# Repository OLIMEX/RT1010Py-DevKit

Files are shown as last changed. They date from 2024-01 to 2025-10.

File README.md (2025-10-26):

# RT1010Py-DevKit
Development board for RT1010Py board

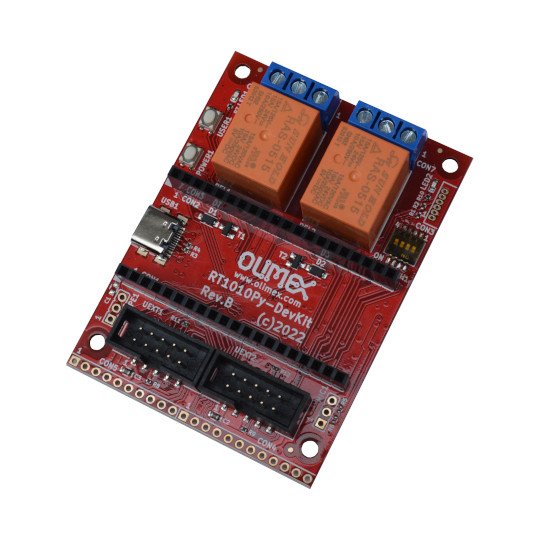
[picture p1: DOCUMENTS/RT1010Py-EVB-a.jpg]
RT1010Py-EVB-a


https://www.olimex.com/Products/MicroPython/RT1010Py-DevKit/open-source-hardware

Features:

* RT1010Py socket connector
* Two UEXT connectors
* Two Relays 10A/250VAC
* USB-C power supply
* Two buttons
* Boot configuration slide switch
* Dimensions: (55 x 75)mm ~ (2.17 x 2.95)"

## Documentation

Check the files in OLIMEX/RT1010Py-DevKit/__DOCUMENTS__ for ressources:

* [RT1010Py-DevKit user manual](DOCUMENTS/RT1010Py-DevKit-user-manual.pdf) (pdf)
* [RT1010Py-DevKit edge connector PinOut](DOCUMENTS/RT1010Py-EVB-edge-connector.jpg) (jpg)
* [RT1010Py-DevKit UEXT PinOut](DOCUMENTS/RT1010Py-EVB-UEXT) (jpg)

See also the [RT1010-Py Microcontroler documentation](https://github.com/OLIMEX/RT1010Py) on its own repository.

## Licenses

* Hardware is released under CERN Open Hardware Licence Version 2 - Strongly Reciprocal, all silkscreen credits to Olimex should remain;
* Software is released under GPL3 Licensee
* Documentation is released under CC BY-SA 4.0

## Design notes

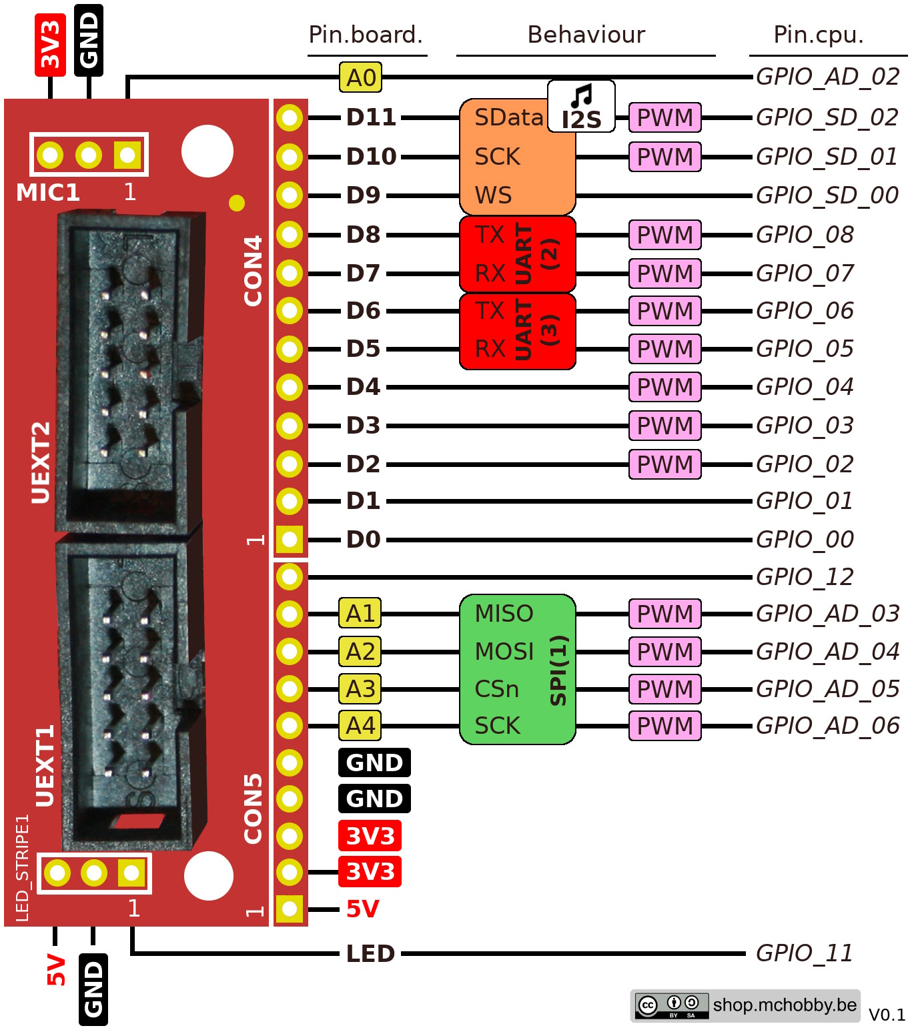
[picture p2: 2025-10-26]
DOCUMENTS/RT1010Py-EVB-edge-connector.jpg

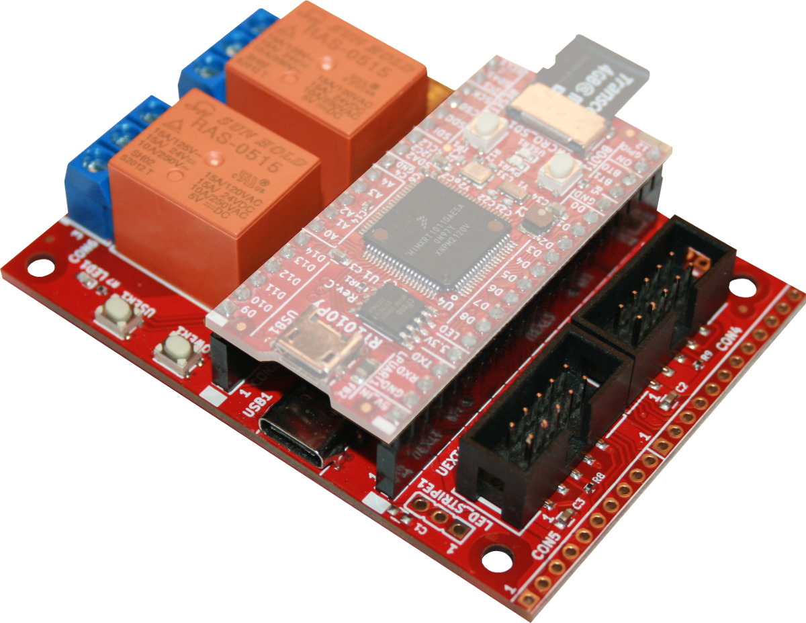
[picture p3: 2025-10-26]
DOCUMENTS/RT1010Py-EVB-b.jpg

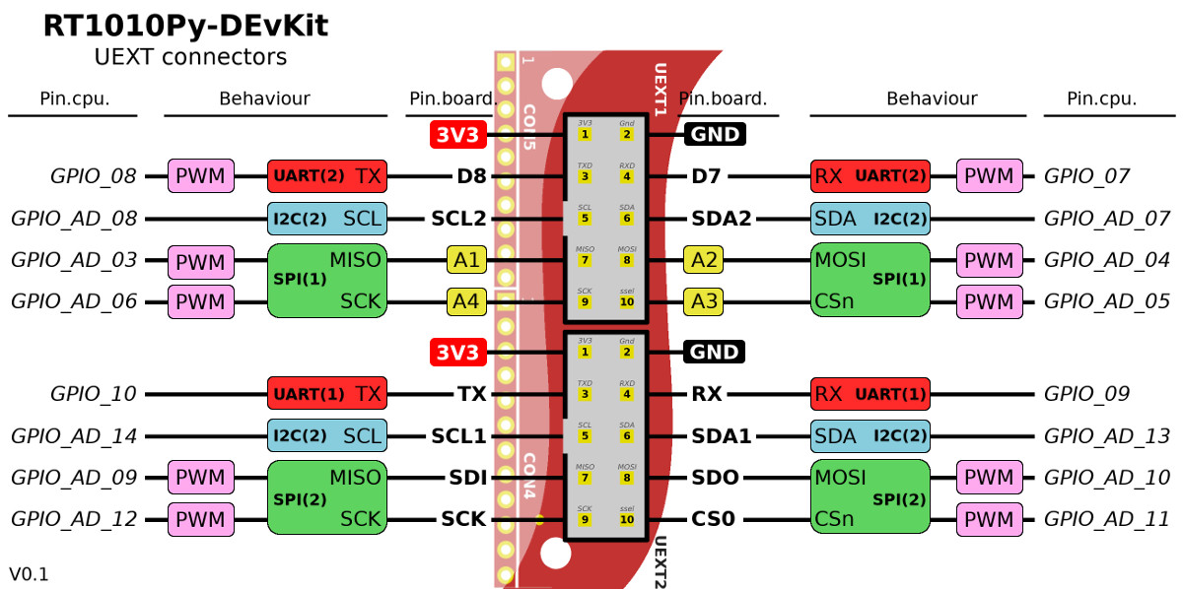
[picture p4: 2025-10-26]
DOCUMENTS/RT1010Py-EVB-UEXT.jpg

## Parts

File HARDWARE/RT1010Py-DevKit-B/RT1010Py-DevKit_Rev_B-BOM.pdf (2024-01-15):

RT1010Py-DevKit_Rev_B-BOM | 06/29/2022
Qty Designation | Package | Designator
4 2.2K/0402 | R_0402_5MIL_DWS | R12,R8,R9,R11
2 5.1K/0402 | R_0402_5MIL_DWS | R3,R4
2 10K/0402 | R_0402_5MIL_DWS | R10,R7
2 4.7uF/6.3V/0603 | C_0603_5MIL_DWS | C3,C2
2 LMUN2211LT1G(SOT-23) SOT23 | T1,T2
2 1N4148W | SOD-123_KA | D2,D1
2 LED/Green/0603 | LED_0603_KA | LED2,LED1
2 BH10S(B-D-02x5-LF) | GBH-254-SMT-10 | UEXT2,UEXT1
2 RAS0515 | Relay_RAS-05-15 | REL2,REL1
2 PN1X20(F-D-1X20-LF) | HN1x20 | CON2,CON1
1 PN_F-D-1x10-LF | PN1x10 | CON5
1 PN_F-D-1X12-LF | PN1x12 | CON4
2 DG306-5.0-3P | TB3-5mm | CON7,CON6
1 USB-C-16P-F | USB2.0_TYPE-C(A40-00119-A52-12) | USB1
1 DSHP04TS-S | DSHP04TS-S-1.27mm_Half_4_Slide | SWITCH1
2 T1107A(6x3,8x2,5MM) | YTS-A016-X | POWER1,USER1
2 NA | HN1x3 | LED_STRIPE1,MIC1
1 NA(WU06S) | WU06S | CON3
2 NA(100K) | R_0402_5MIL_DWS | R6,R5
1 NA(4.7uF/6.3V) | C_0603_5MIL_DWS | C1
2 NA(220R) | R_0402_5MIL_DWS | R1,R2

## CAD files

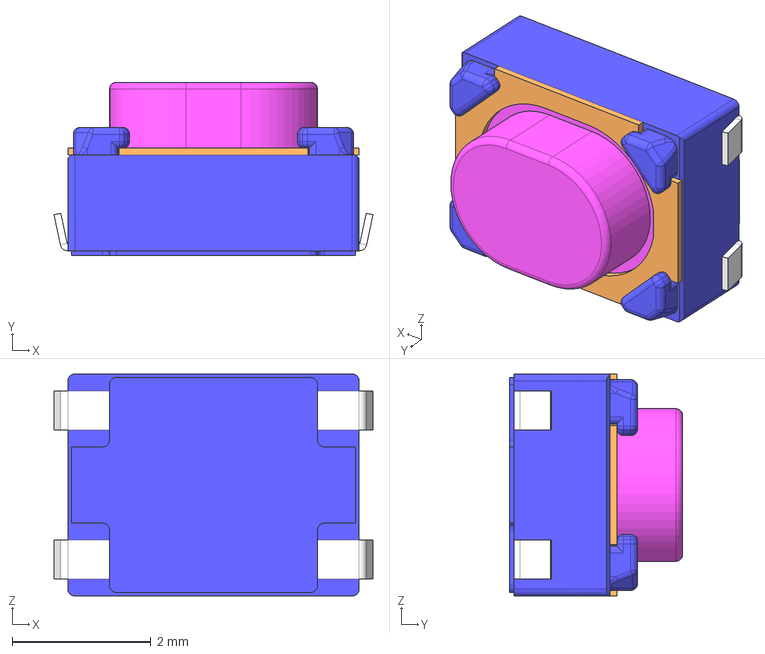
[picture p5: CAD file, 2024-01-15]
HARDWARE/RT1010Py-DevKit-B/3d/YTS-A016-X(SKRPABE010).stp
4.60 x 2.50 x 3.20 mm

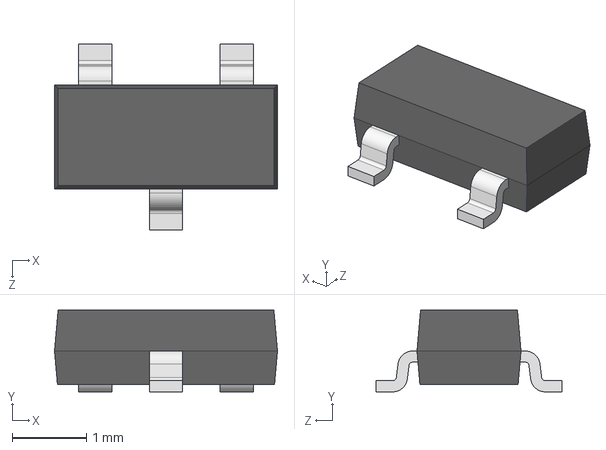
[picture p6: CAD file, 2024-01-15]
HARDWARE/RT1010Py-DevKit-B/3d/SOT-23.step
3.00 x 1.10 x 2.50 mm

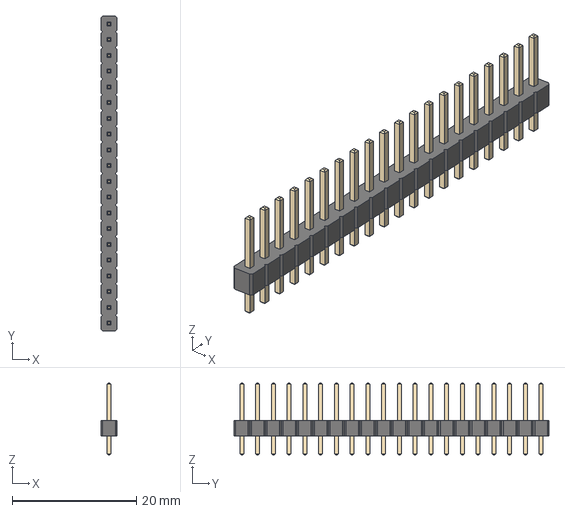
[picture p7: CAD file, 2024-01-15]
HARDWARE/RT1010Py-DevKit-B/3d/HN1x20-PinHeader_1x20_P2.54mm_Vertical.step
2.54 x 50.8 x 11.5 mm

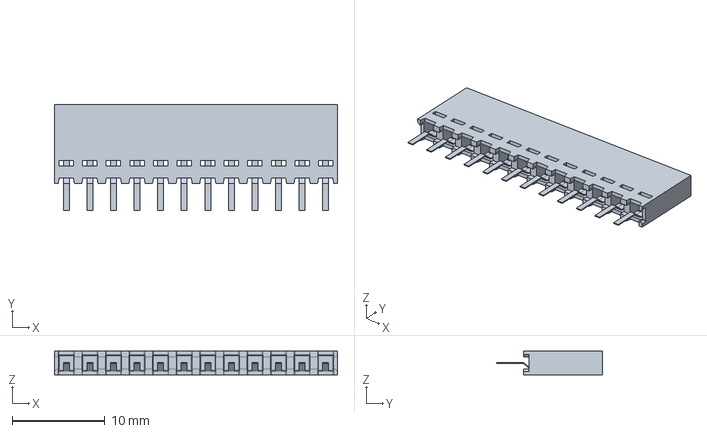
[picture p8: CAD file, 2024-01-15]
HARDWARE/RT1010Py-DevKit-B/3d/PN1x12-Molex_C-Grid_901471112_1x12_P2.54mm_Vertical.step
30.5 x 11.4 x 2.54 mm

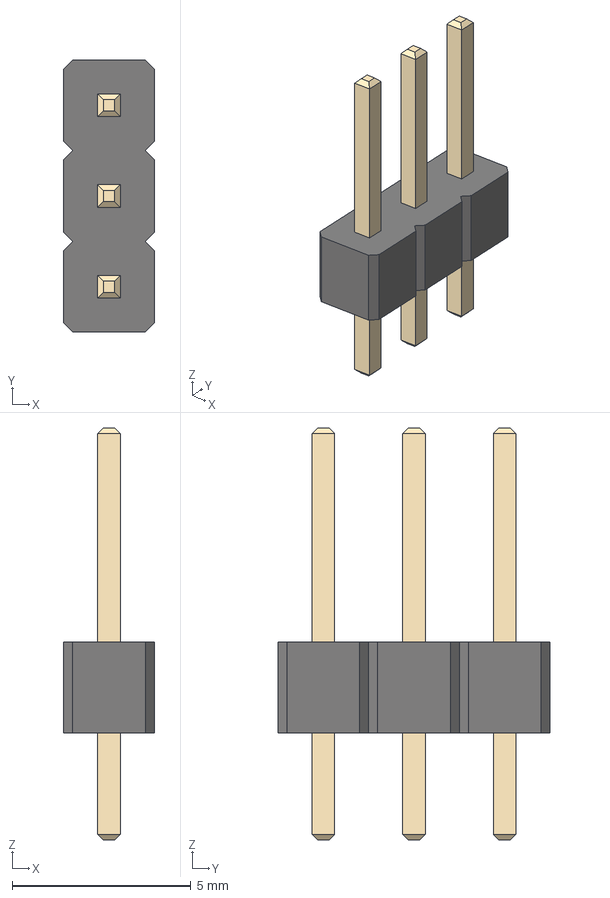
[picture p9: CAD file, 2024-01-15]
HARDWARE/RT1010Py-DevKit-B/3d/HN1x3-PinHeader_1x03_P2.54mm_Vertical.step
2.54 x 7.62 x 11.5 mm

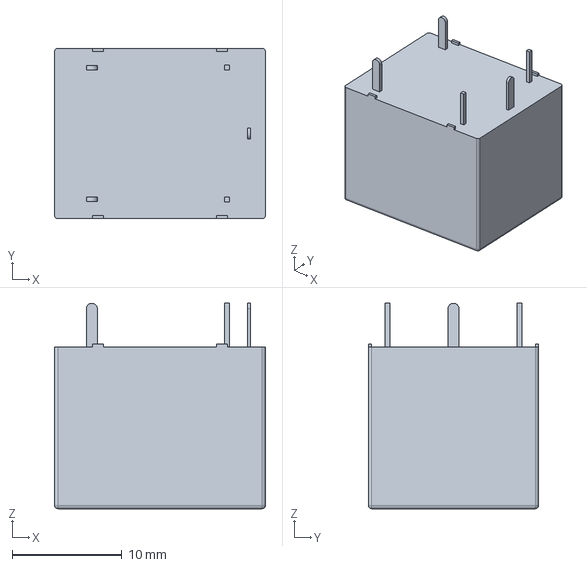
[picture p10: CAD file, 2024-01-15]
HARDWARE/RT1010Py-DevKit-B/3d/TEConnectivity -ORWH-SH-124D1F000.stp
19.2 x 15.5 x 18.7 mm

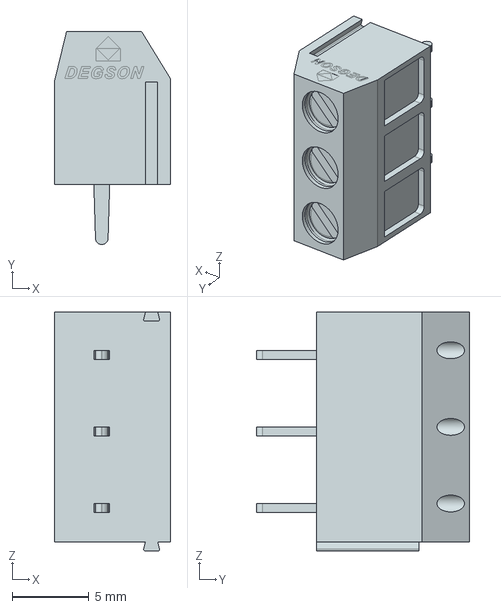
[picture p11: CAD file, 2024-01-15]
HARDWARE/RT1010Py-DevKit-B/3d/TB3-5MM_DG306-5.0-03P-1Y-00A(H).stp
7.60 x 13.9 x 15.6 mm

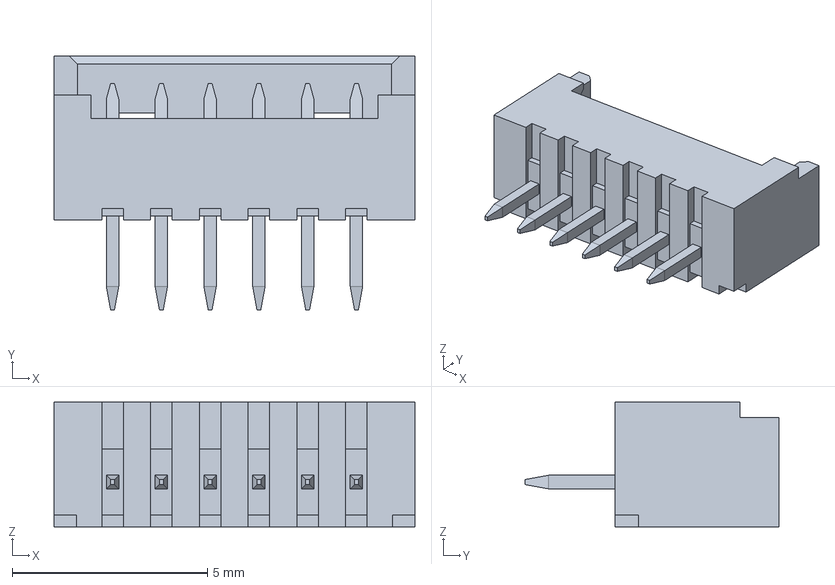
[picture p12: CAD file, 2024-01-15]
HARDWARE/RT1010Py-DevKit-B/3d/WU06S-Molex_PicoBlade_530470610_1x06_P1.25mm_Vertical.step
9.25 x 6.50 x 3.20 mm

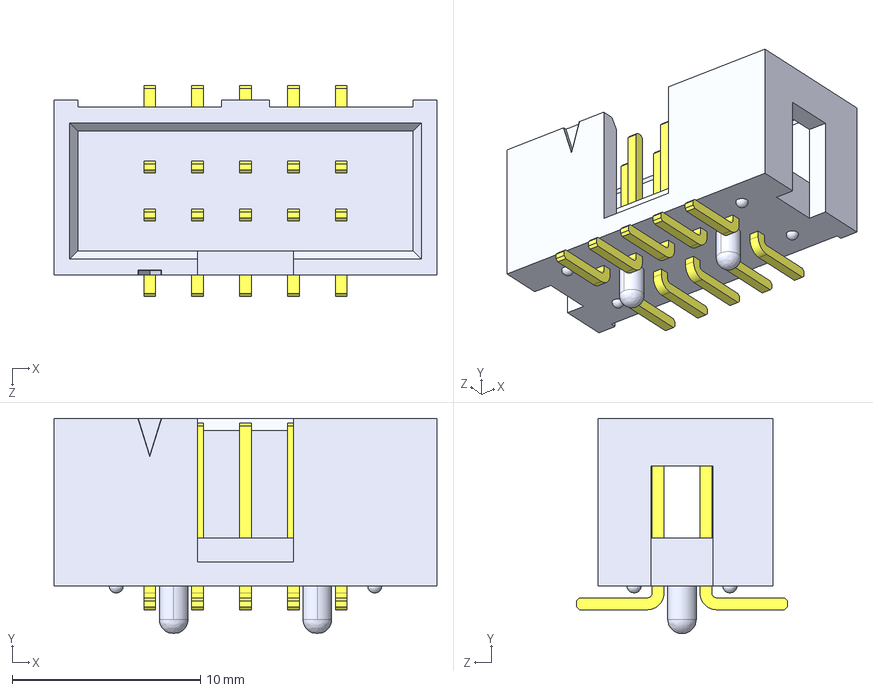
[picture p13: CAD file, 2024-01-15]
HARDWARE/RT1010Py-DevKit-B/3d/UEXT-SMD.STEP
20.3 x 11.4 x 11.2 mm
User Library-HTST-105-01-F-DV-A__HTST-105-01-DV-A_header
User Library-HTST-105-01-F-DV-A__HTST-First_Position_Indicator
User Library-HTST-105-01-F-DV-A__T-1S6-05-01-DV_

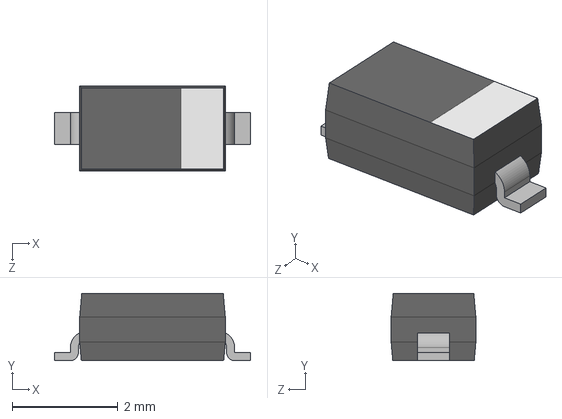
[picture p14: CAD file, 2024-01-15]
HARDWARE/RT1010Py-DevKit-B/3d/SOD123.step
3.70 x 1.27 x 1.60 mm

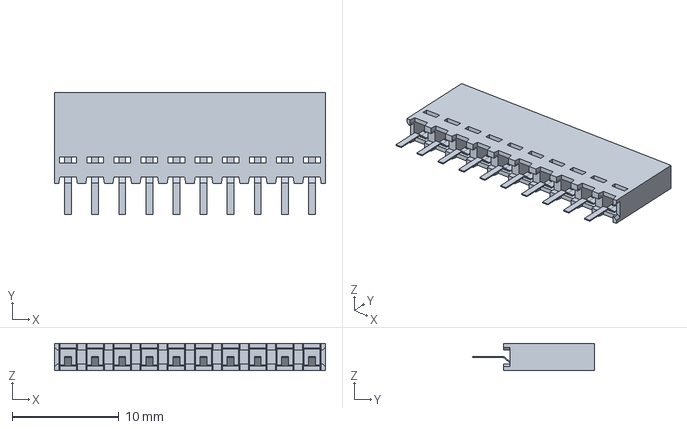
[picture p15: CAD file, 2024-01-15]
HARDWARE/RT1010Py-DevKit-B/3d/PN1x10-Molex_C-Grid_901471110_1x10_P2.54mm_Vertical.step
25.4 x 11.4 x 2.54 mm

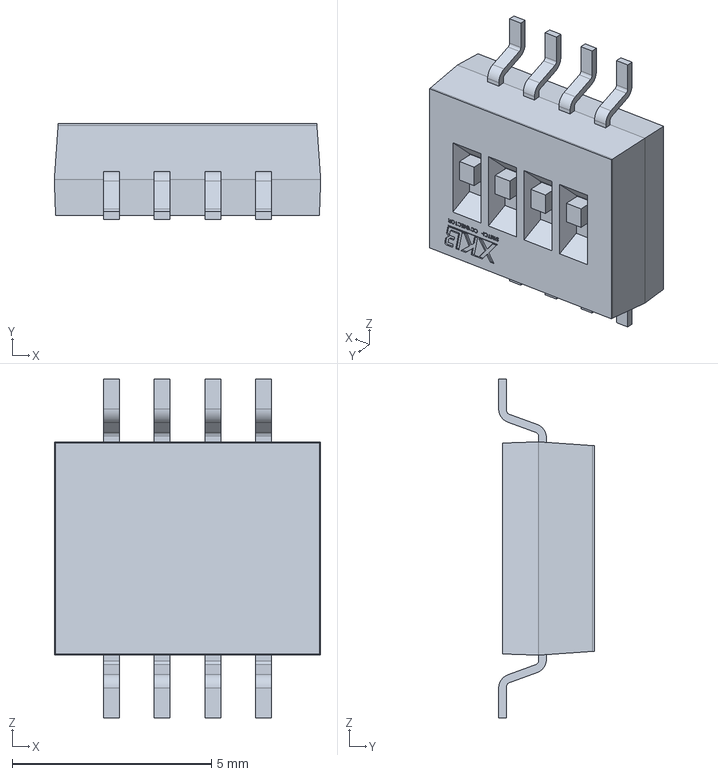
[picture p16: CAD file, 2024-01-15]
HARDWARE/RT1010Py-DevKit-B/3d/dshp04ts-s.stp
6.68 x 2.40 x 8.50 mm

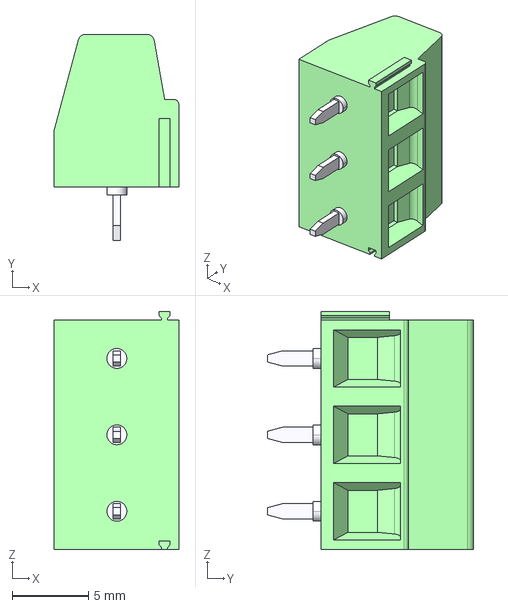
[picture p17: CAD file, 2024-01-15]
HARDWARE/RT1010Py-DevKit-B/3d/70054376.stp
8.15 x 13.5 x 15.6 mm

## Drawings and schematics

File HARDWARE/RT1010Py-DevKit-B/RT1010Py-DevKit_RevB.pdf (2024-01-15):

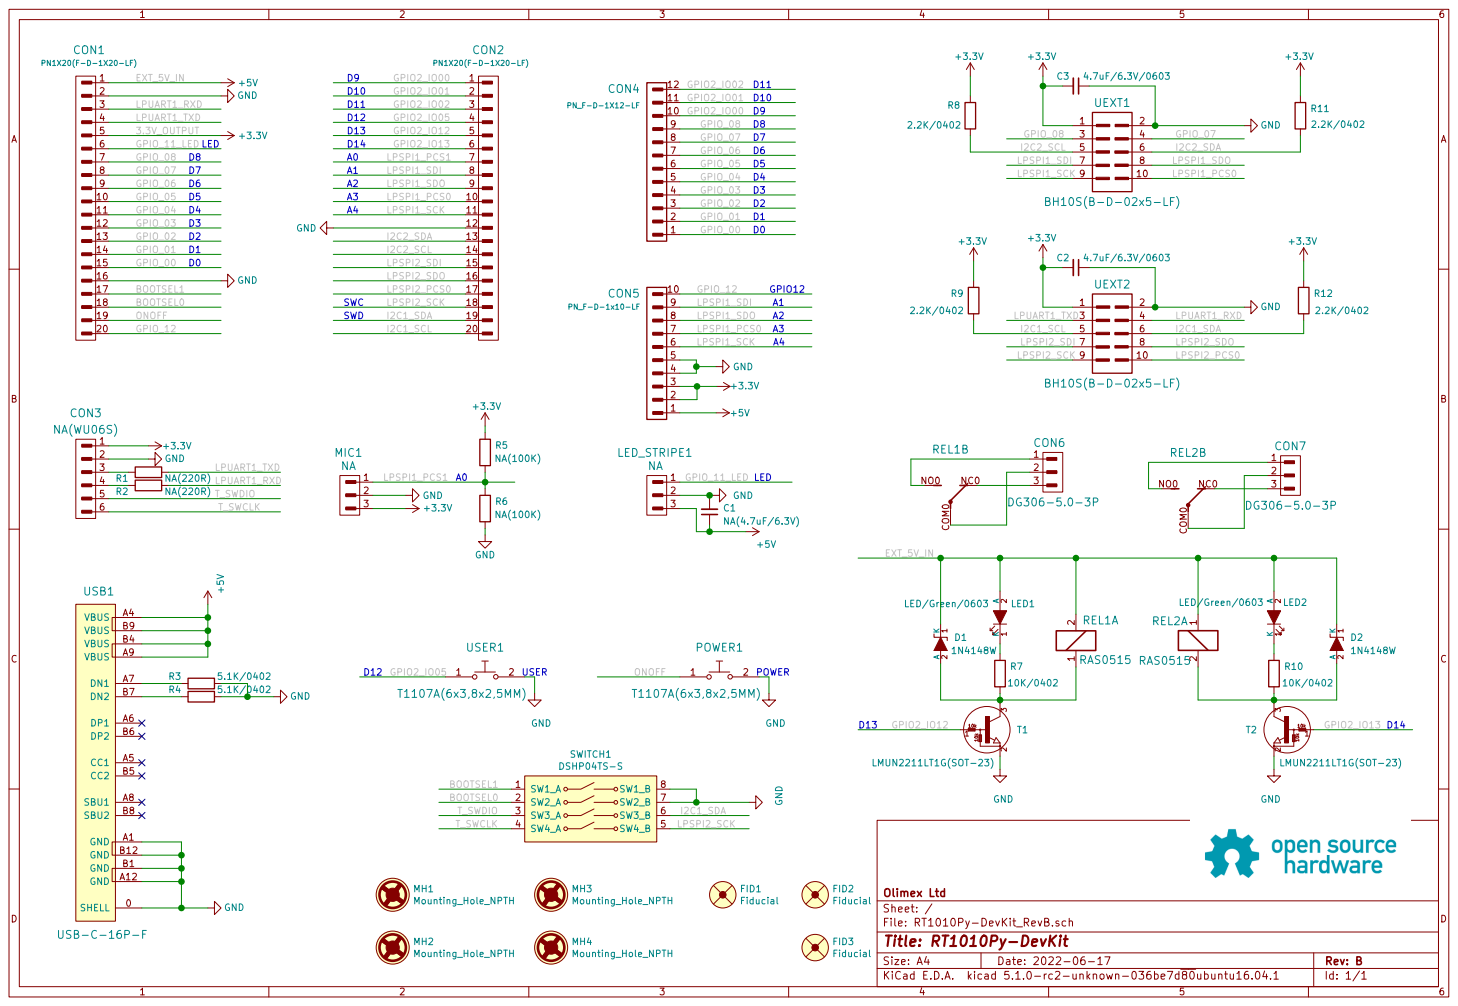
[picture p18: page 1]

File: RT1010Py-DevKit_RevB.sch Sheet: / Olimex Ltd

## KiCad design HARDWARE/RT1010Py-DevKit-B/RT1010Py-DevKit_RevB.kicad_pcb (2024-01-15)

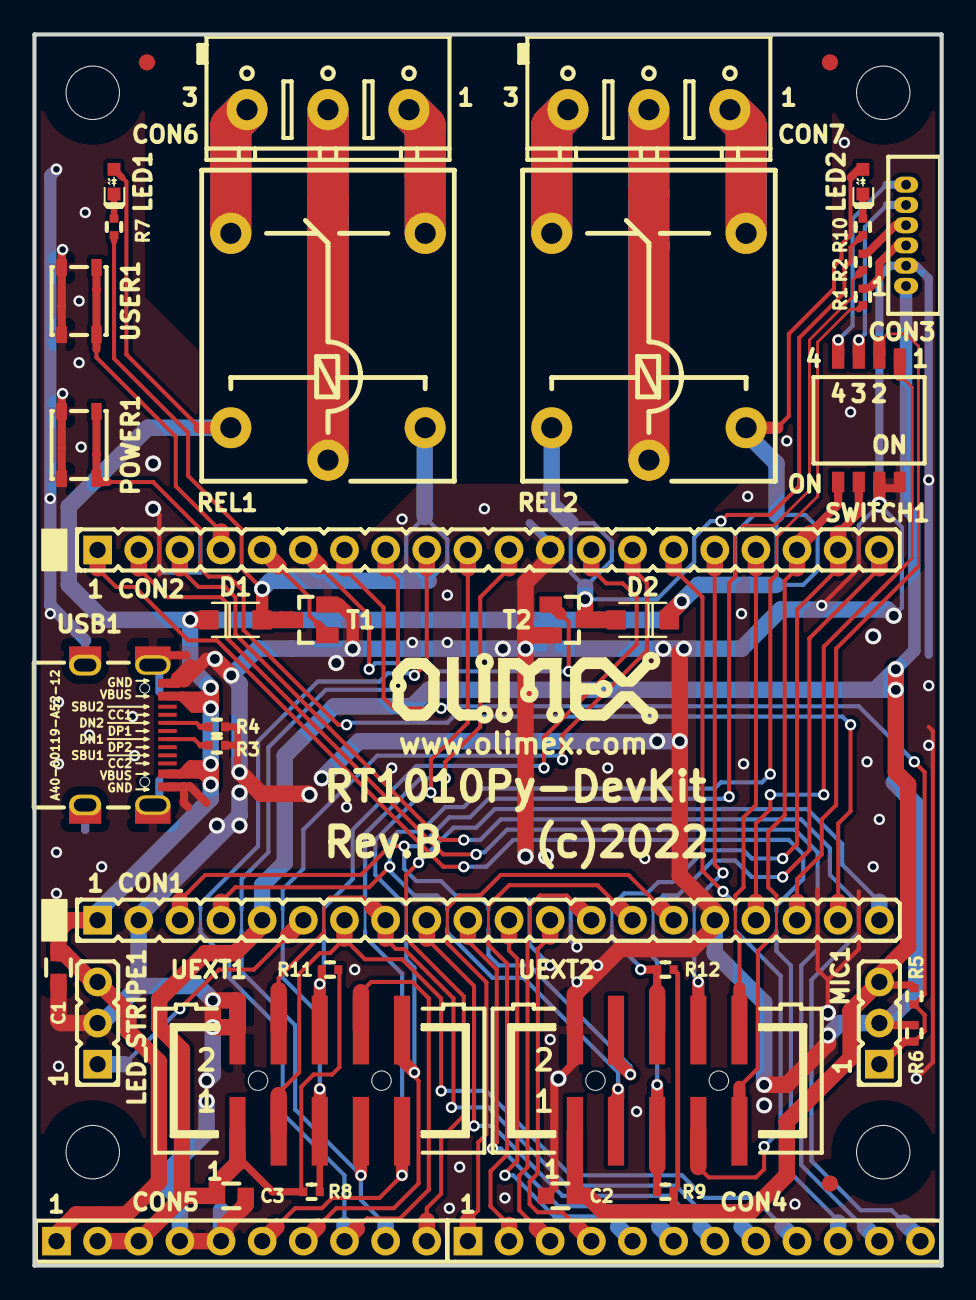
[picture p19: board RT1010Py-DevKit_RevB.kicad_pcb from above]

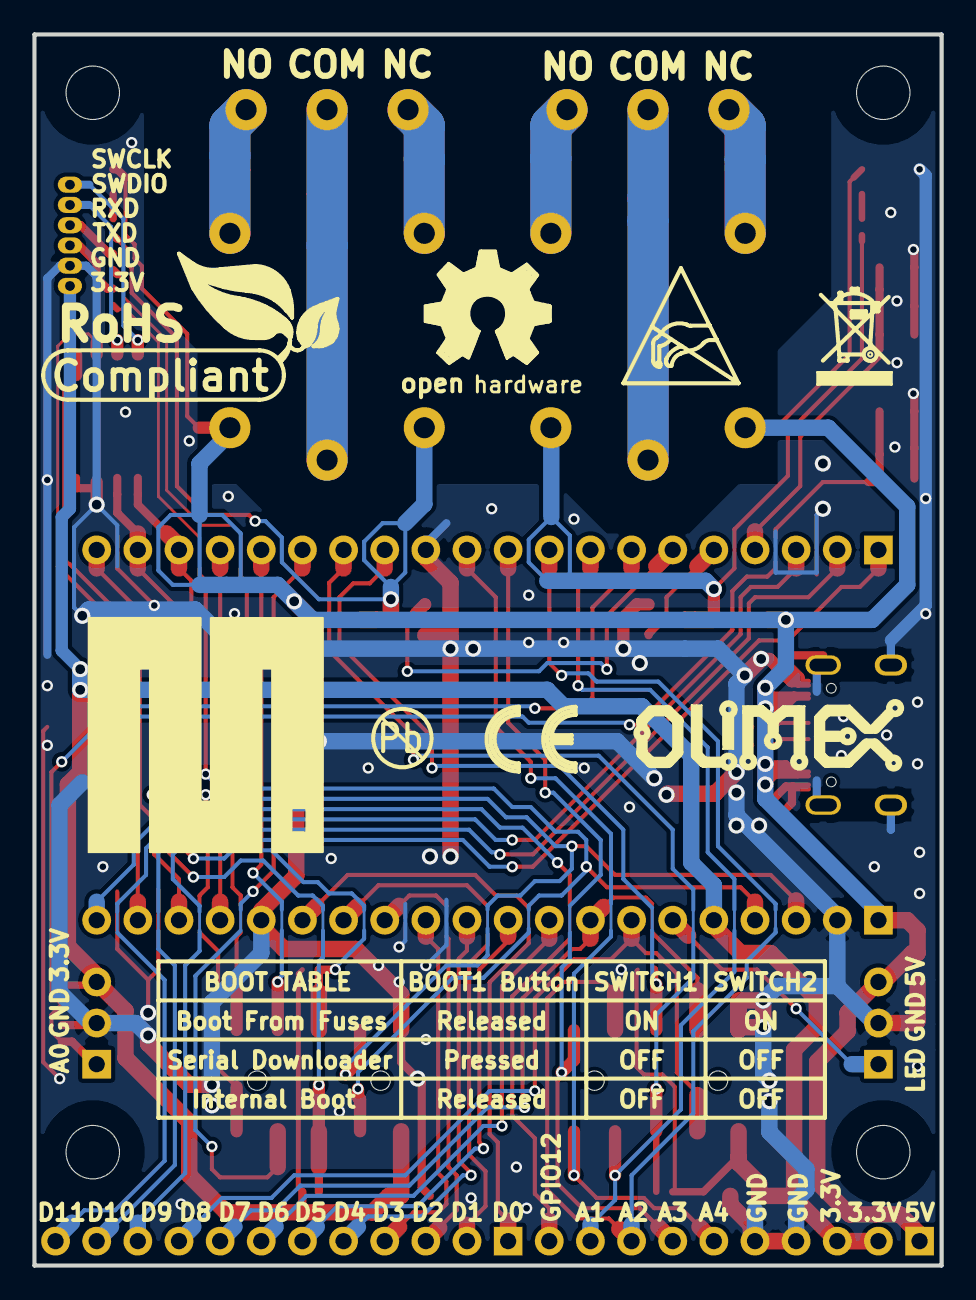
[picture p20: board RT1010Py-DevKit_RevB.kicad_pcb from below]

Board: 2 copper layers, 56.0 x 76.0 mm, 54 parts (8 on the bottom side), 54 nets.

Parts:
C1: NA(4.7uF/6.3V); C_0603_5MIL_DWS
C2, C3: 4.7uF/6.3V/0603; C_0603_5MIL_DWS
CE_Sign: CE_Sign
CON1, CON2: PN1X20(F-D-1X20-LF); HN1x20
CON3: NA(WU06S); WU06S
CON4: PN_F-D-1X12-LF; PN1x12
CON5: PN_F-D-1x10-LF; PN1x10
CON6, CON7: DG306-5.0-3P; TB3-5mm
D1, D2: 1N4148W; SOD-123_KA
FID1, FID2, FID3: Fiducial; Fiducial1x3
LED1, LED2: LED/Green/0603; LED_0603_KA
LED_STRIPE1: NA; HN1x3
MH1, MH2, MH3, MH4: Mounting_Hole_NPTH; Mounting_hole_3.3mm
MIC1: NA; HN1x3
MicroPython_Logo: LOGO; MicroPython_Logo
Olimex_Logo, Olimex_Logo1: OLIMEX_LOGO_TB
Open_Hardware: LOGO_OPENHARDWARE_8x8
POWER1: T1107A(6x3,8x2,5MM); YTS-A016-X
R1, R2: NA(220R); R_0402_5MIL_DWS
R3, R4: 5.1K/0402; R_0402_5MIL_DWS
R5, R6: NA(100K); R_0402_5MIL_DWS
R7, R10: 10K/0402; R_0402_5MIL_DWS
R8, R9, R11, R12: 2.2K/0402; R_0402_5MIL_DWS
REL1, REL2: RAS0515; Relay_RAS-05-15
Recycle: LOGO_RECYCLEBIN_1
SWITCH1: DSHP04TS-S; DSHP04TS-S-1.27mm_Half_4_Slide
Sign_Antistatic: Sign_Antistatic
Sign_PB-Free: Sign_PB-Free
Sign_RoHS_1: Sign_RoHS_1
T1, T2: LMUN2211LT1G(SOT-23); SOT23
UEXT1, UEXT2: BH10S(B-D-02x5-LF); GBH-254-SMT-10
USB1: USB-C-16P-F; USB2.0_TYPE-C(A40-00119-A52-12)
USER1: T1107A(6x3,8x2,5MM); YTS-A016-X

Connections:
+3.3V: C2.2, C3.2, CON1.5, CON3.1, CON5.2, CON5.3, MIC1.3, R5.2, R8.2, R9.2, R11.2, R12.2, UEXT1.1, UEXT2.1
+5V: C1.1, CON1.1, CON5.1, D1.1, D2.1, LED1.2, LED2.2, LED_STRIPE1.3, REL1.2, REL2.1, USB1.A4, USB1.A9, USB1.B4, USB1.B9
/BOOTSEL0: CON1.18, SWITCH1.2
/BOOTSEL1: CON1.17, SWITCH1.1
/GPIO2_IO00: CON2.1, CON4.10
/GPIO2_IO01: CON2.2, CON4.11
/GPIO2_IO02: CON2.3, CON4.12
/GPIO2_IO05: CON2.4, USER1.1
/GPIO2_IO12: CON2.5, T1.1
/GPIO2_IO13: CON2.6, T2.1
/GPIO_00: CON1.15, CON4.1
/GPIO_01: CON1.14, CON4.2
/GPIO_02: CON1.13, CON4.3
/GPIO_03: CON1.12, CON4.4
/GPIO_04: CON1.11, CON4.5
/GPIO_05: CON1.10, CON4.6
/GPIO_06: CON1.9, CON4.7
/GPIO_07: CON1.8, CON4.8, UEXT1.4
/GPIO_08: CON1.7, CON4.9, UEXT1.3
/GPIO_11_LED: CON1.6, LED_STRIPE1.1
/GPIO_12: CON1.20, CON5.10
/I2C1_SCL: CON2.20, R9.1, UEXT2.5
/I2C1_SDA: CON2.19, R12.1, SWITCH1.6, UEXT2.6
/I2C2_SCL: CON2.14, R8.1, UEXT1.5
/I2C2_SDA: CON2.13, R11.1, UEXT1.6
/LPSPI1_PCS0: CON2.10, CON5.7, UEXT1.10
/LPSPI1_PCS1: CON2.7, MIC1.1, R5.1, R6.2
/LPSPI1_SCK: CON2.11, CON5.6, UEXT1.9
/LPSPI1_SDI: CON2.8, CON5.9, UEXT1.7
/LPSPI1_SDO: CON2.9, CON5.8, UEXT1.8
/LPSPI2_PCS0: CON2.17, UEXT2.10
/LPSPI2_SCK: CON2.18, SWITCH1.5, UEXT2.9
/LPSPI2_SDI: CON2.15, UEXT2.7
/LPSPI2_SDO: CON2.16, UEXT2.8
/LPUART1_RXD: CON1.3, R2.1, UEXT2.4
/LPUART1_TXD: CON1.4, R1.1, UEXT2.3
/ONOFF: CON1.19, POWER1.1
/T_SWCLK: CON3.6, SWITCH1.4
/T_SWDIO: CON3.5, SWITCH1.3
GND: C1.2, C2.1, C3.1, CON1.2, CON1.16, CON2.12, CON3.2, CON5.4, CON5.5, LED_STRIPE1.2, MIC1.2, POWER1.2, R3.1, R4.1, R6.1, SWITCH1.7, SWITCH1.8, T1.2, T2.2, UEXT1.2, UEXT2.2, USB1.0, USB1.A1, USB1.A12, USB1.B1, USB1.B12, USER1.2
unnamed: CON3.3, R1.2
unnamed: CON3.4, R2.2
unnamed: CON6.1, REL1.NO0
unnamed: CON6.2, REL1.COM0
unnamed: CON6.3, REL1.NC0
unnamed: CON7.1, REL2.NO0
unnamed: CON7.2, REL2.COM0
unnamed: CON7.3, REL2.NC0
unnamed: D1.2, R7.1, REL1.1, T1.3
unnamed: D2.2, R10.1, REL2.2, T2.3
unnamed: LED1.1, R7.2
unnamed: LED2.1, R10.2
unnamed: R3.2, USB1.A7
unnamed: R4.2, USB1.B7

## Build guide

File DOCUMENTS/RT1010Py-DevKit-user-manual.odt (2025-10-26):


RT1010Py-DevKit

User Manual

Rev.1.1 Oct. 2025 olimex.com

# Revision

Revision | Date | By | Description
1.0 | Jan. 2024 | TsvetanUsunov | Initial document
1.1 | Oct. 2025 | Meurisse D. | Adding content and details

# What is RT1010Py-DevKit

RT1010Py-DevKit is development board for RT1010Py module.


RT1010Py-DevKit has these features:

- Socket for RT1010Py
- USB-C power supply input
- Two buttons
- Two relays 10A/250VAC
- Two UEXT connectors
- Boot configuration slide switch
- Dimensions: (55 x 75)mm ~ (2.17 x 2.95)"

## Order codes for RT1010Py-DevKit and accessories

RT1010Py-DevKit (https://www.olimex.com/Products/MicroPython/RT1010Py-DevKit/open-source-hardware) evaluation board for RT1010Py (https://www.olimex.com/Products/MicroPython/RT1010-Py/open-source-hardware) with two relays, two UEXT, USB-C

RT1010Py (https://www.olimex.com/Products/MicroPython/RT1010-Py/open-source-hardware) RT1011 board running at 500Mhz with MicroPython

USB-CABLE-A-MICRO-1.8M (https://www.olimex.com/Products/Components/Cables/USB-CABLE-A-MICRO-1.8M/) USB-A to micro cable

MICRO-SD-16GB-CLASS10 (https://www.olimex.com/Products/Components/Storage/MICRO-SD-16GB-CLASS10/) 16GB microSD card

UEXT modules (https://www.olimex.com/Products/Modules/) There are temperature, humidity, pressure, magnetic field, light sensors. Modules with LCDs, LED matrix, Relays, Bluetooth, Zigbee, WiFi, GSM, GPS, RFID, RTC, EKG, sensors and etc.

# HARDWARE

## RT1010PyDevKit layout

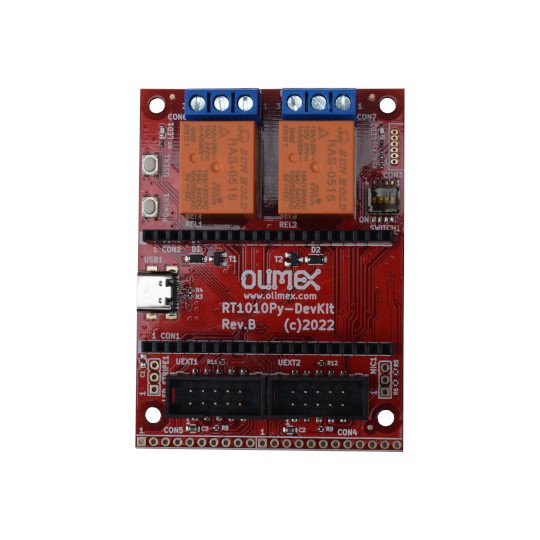
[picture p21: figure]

Relay 1 and 2

Relay 1 activity LED

Relay 2 activity LED

CON3 debug

Boot config

Power USB-C

Power button

User button

LED stripe

Microphone

RT1010Py signals

UEXT1

UEXT2

## RT1010Py-DevKit schematics

RT1010Py-DevKit (https://www.olimex.com/Products/MicroPython/RT1010Py-DevKit/open-source-hardware) latest schematic is on GitHub (https://github.com/OLIMEX/RT1010Py-DevKit/blob/main/HARDWARE/RT1010Py-DevKit-B/RT1010Py-DevKit_RevB.pdf)

## RT1010Py GPIOs

Le following picture remind the RT1010Py pinout.

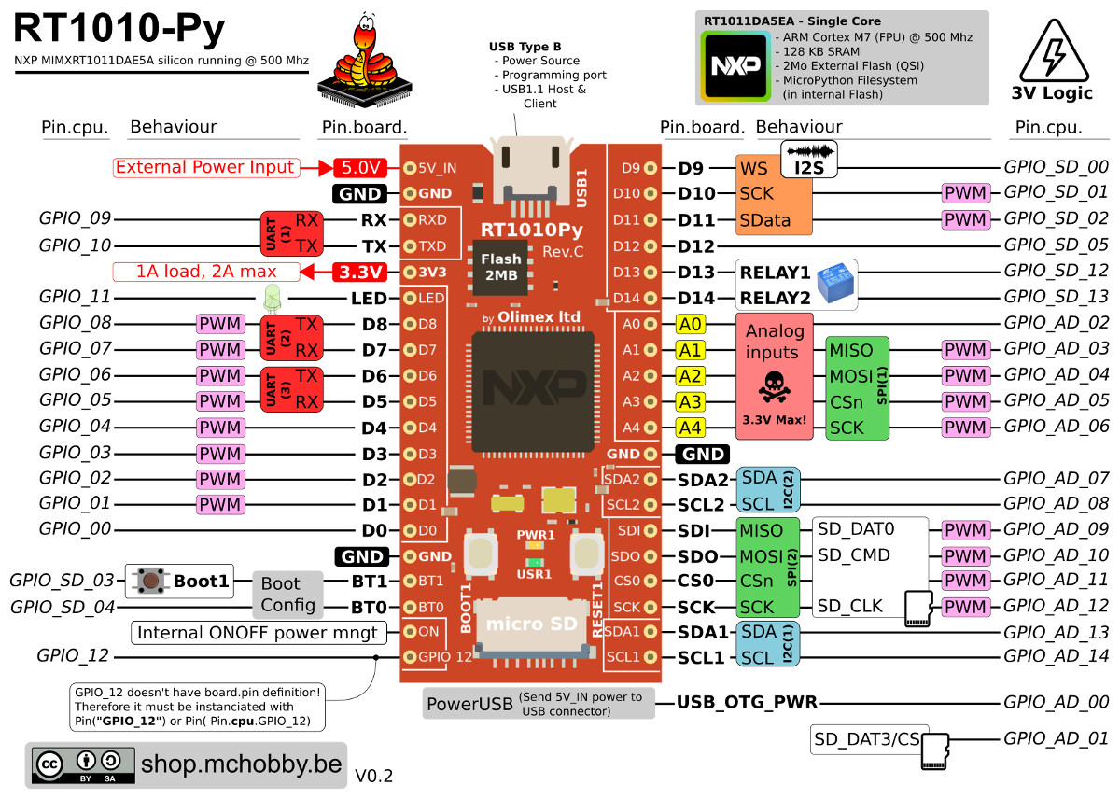
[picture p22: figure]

## DevKit GPIO connectors

The DevKit GPIO connector is designed to receive the RT1010Py microcontroler

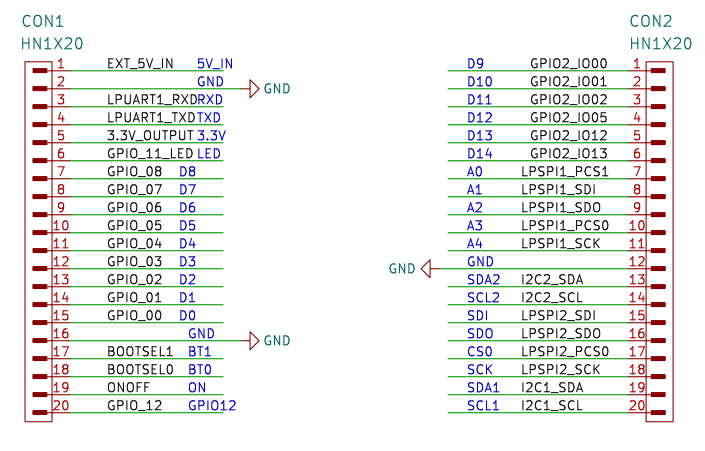
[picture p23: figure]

Here some useful details regarding the usage of some GPIO on the DevKit.

- 5V_IN: This pin receive the 5V voltage coming from the USB-C. This pin will also power the RT1010Py MCU.
- RX: UART(1) RX also connected to debug connector pin #4 (220Ω must be populated).
- TX: UART(1) TX also connected to debug connector pin #3 (220Ω must be populated).
- 3V3: The 3.3V voltage generated by the MCU regulator when the MCU is powered from its own micro-USB or from the USB-C (via 5V_IN pin).
- LED: The MCU User1 LED (green) is connected on that pin. LED is also connected on “LED Stripe” connector pin #1.
- BT1, BT0: allows to control the boot sequence. The pins are attached to DIP switch #1 & #2 (on right side of the relays). Place them up toward the relay terminal (switch is open) to run MicroPython at boot.
- ON: connected to the Power button (on left side of relays). This button controls the RT1010Py power management unit (see RT1010Py manual for details).
- D12: is connected to the User1 button (on left side of relays).
- D13, D14: activates the relay 1 (left one) and relay 2 (right one) when the signal is set HIGH. Note: MicroPython firmware defines RELAY1, RELAY2 as alias for pin D13, D14.
- A0: connected on the MIC connector pin #1.
- SCK: also SWCLK in debug mode. Can be connected to debug connector pin #6 when the DIP switch #4 is placed down (toward the microcontroler).
- SDA1: also SWDIO in debug mode. Can be connected to debug connector pin #5 when the DIP switch #3 is placed down (toward the microcontroler).

## DevKit Edge connector

Most of the GPIOs are also broken out on the edge connector (see CON4, CON5).


## UEXT connectors

UEXT connector stands for Universal EXTension connector and contain +3.3V, GND, I2C, SPI, UART signals. All signals are with 3.3V levels.

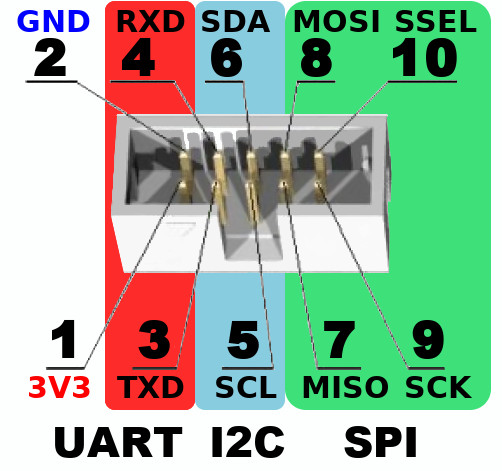
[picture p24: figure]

Olimex has developed number of MODULES (https://www.olimex.com/Products/Modules/) with this connector. There are temperature, humidity, pressure, magnetic field, light sensors. Modules with LCDs, LED matrix, Relays, Bluetooth, Zigbee, WiFi, GSM, GPS, RFID, RTC, EKG, sensors and etc.

The RT1010Py-DevKit is fitted with two original size UEXT connectors (0.1”/2.54mm step boxed plastic connector, note that UEXT also exists in mini, pico and flat format).


# SOFTWARE

Controling buses, analog input and IO are described in the RT1010Py User Manual.

Check it at https://github.com/OLIMEX/RT1010Py/tree/main/DOCUMENTS

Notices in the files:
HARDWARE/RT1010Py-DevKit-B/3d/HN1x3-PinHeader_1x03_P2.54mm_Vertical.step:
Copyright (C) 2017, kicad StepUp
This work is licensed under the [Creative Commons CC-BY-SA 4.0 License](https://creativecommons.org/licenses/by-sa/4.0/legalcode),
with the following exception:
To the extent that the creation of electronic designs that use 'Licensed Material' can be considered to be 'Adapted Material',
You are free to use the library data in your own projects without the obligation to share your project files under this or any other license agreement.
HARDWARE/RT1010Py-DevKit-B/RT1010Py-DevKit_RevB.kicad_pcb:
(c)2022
